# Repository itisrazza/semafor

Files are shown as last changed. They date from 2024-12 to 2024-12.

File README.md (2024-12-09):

# Semafor

This is the code and resources for a wee traffic light project I'm working on.

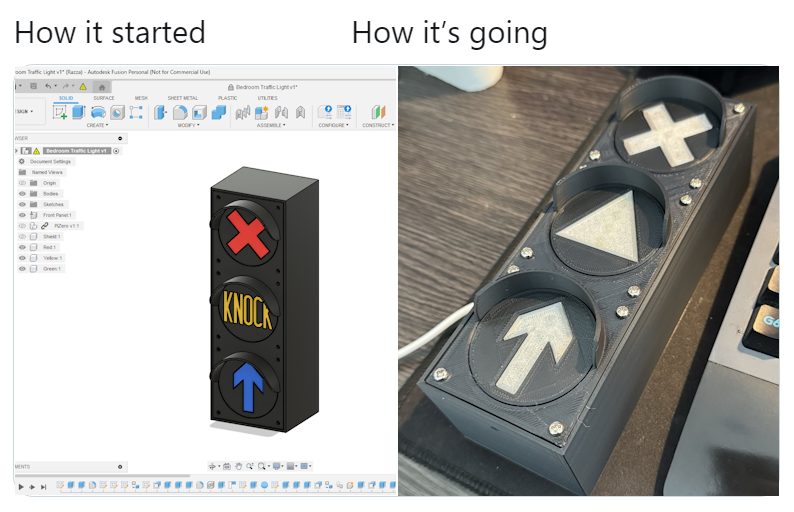
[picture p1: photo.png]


I've already built it, but I need to put together some nice photos of it. Here's a link to the [hardware README](hardware/README.md) if you want to build your own.

## Licence

This is a hobby project, and I encourage you to copy it and do whatever, but please credit, share alike and all that:

[Software](semafor) is licenced under the [GNU Affero General Public License v3+](LICENCE.AGPLv3+)

Everything else is [CC BY-SA 4.0](LICENCE.CC-BY-SA-4).

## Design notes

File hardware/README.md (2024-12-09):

# Semafor Hardware

## Bill of Meterials

Below are the things I used to put it together.

- 3D Printing Filament

  - Black PLA
  - Translucent PETG

- Electronics

  - [Raspberry Pi Zero W](https://www.pbtech.co.nz/product/SEVRBP0412/Raspberry-Pi-Zero-W-1GHz-BCM2835-Single-Core-CPU-5) with GPIO headers, and an SD card
  - [LEDs](https://www.aliexpress.com/item/1005003323707856.html)
    - 5x Red LEDs
    - 4x Yellow LEDs
    - 4x Green LEDs
  - [Prototype boards](https://www.aliexpress.com/item/1005006046334726.html)
    - 1x 2x8cm
    - 1x 3x7cm
  - 3x 330&Omega; resistors
  - [Any to Female Dupont Cable](https://www.aliexpress.com/item/1005005501503609.html)

- a number of M3x6mm and M3x10mm screws

## Build Instrucutions

### LED Assemblies

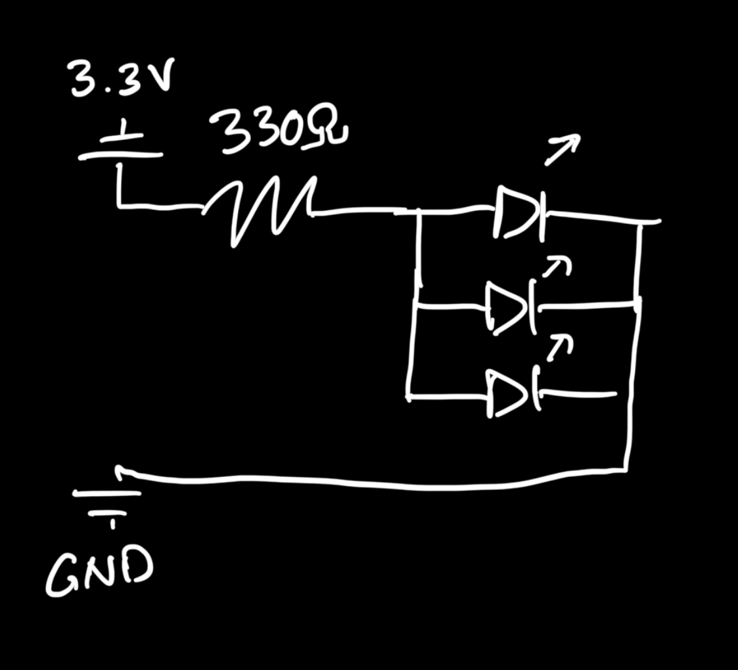
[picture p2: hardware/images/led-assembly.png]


The clear LED prints show what the spacing between the LEDs should be. Place them on the prototype-boards accordingly and connect them in parallel.

Add a 330&Omega; resistor in between the 3.3V power input and the LED power rail.

The power cables have a female Dupont connector on the Raspberry Pi end so they can be replace should the LEDs burn out, or a new design is desired.

Use [hot glue liberally](images/hot-glue.png) (optional, but I didn't have my own custom printed PCBs and didn't want to short anything by accident).

### Main Assembly

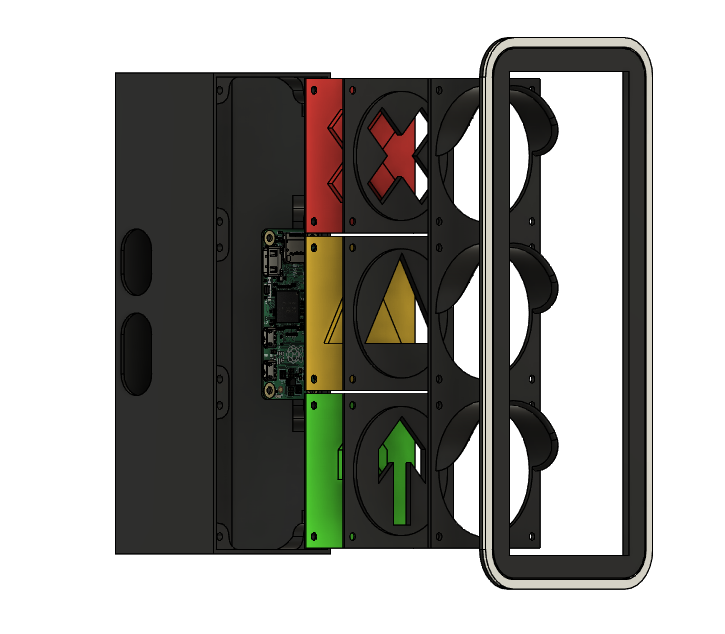
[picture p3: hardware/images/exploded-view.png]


1. Install the Raspberry Pi Zero into the Enclosure with 4 M3x6mm screws
2. Connect the LED assemblies to the following pins:
   - Red to [GPIO 17](https://pinout.xyz/pinout/pin11_gpio17/)
   - Yellow to [GPIO 27](https://pinout.xyz/pinout/pin13_gpio27/)
   - Green to [GPIO 22](https://pinout.xyz/pinout/pin15_gpio22/)
   - Grounds to [any ground pin](https://pinout.xyz/pinout/ground)
3. You may want to boot up the Pi and make sure everything works\
   (You can just use Python and the builtin `gpiozero` library)
4. Place the LED masks and front panel over the front.
5. Screw in place with 12 M3x6mm

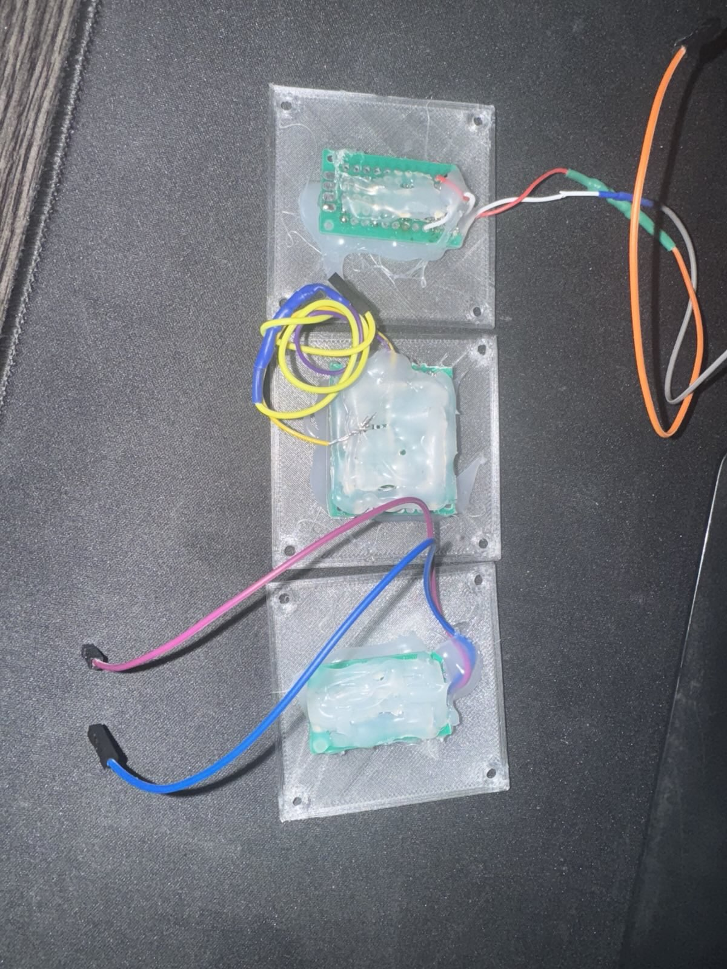
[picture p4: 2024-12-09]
hardware/images/hot-glue.png

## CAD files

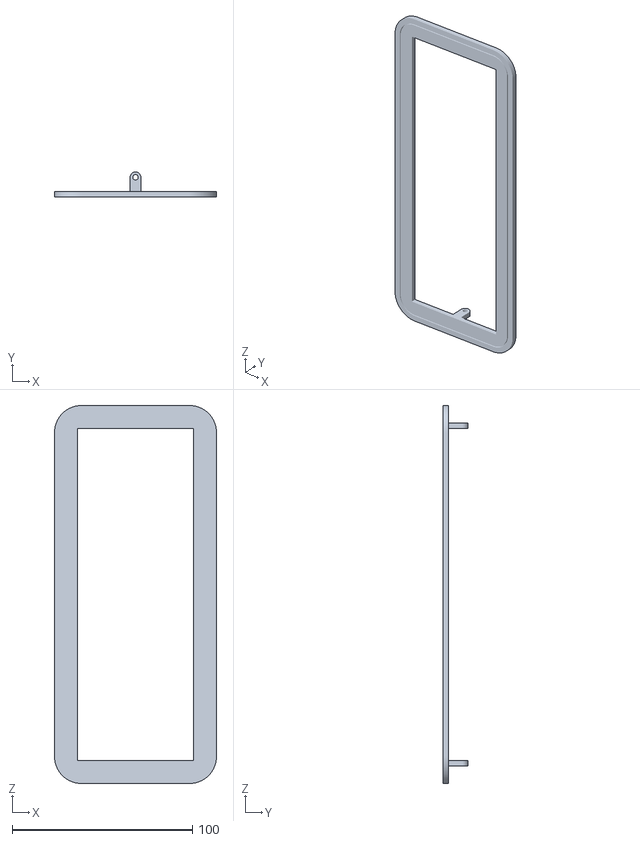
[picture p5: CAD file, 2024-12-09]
hardware/stl/Shield.stl
90.0 x 14.0 x 210.0

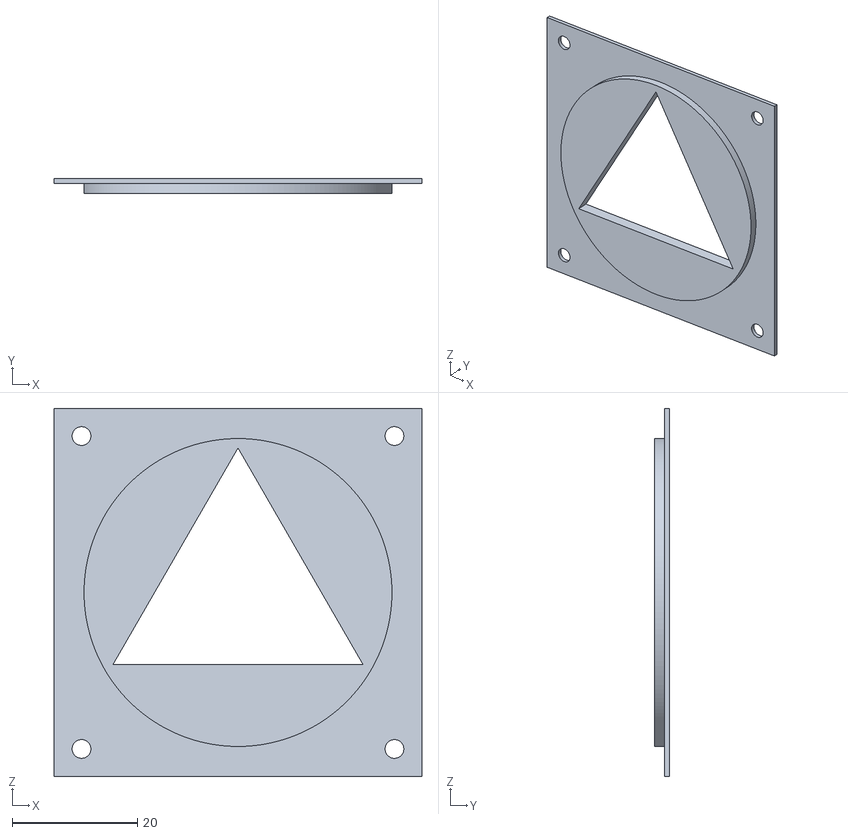
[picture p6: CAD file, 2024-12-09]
hardware/stl/Yellow Mask.stl
58.8 x 2.40 x 58.8

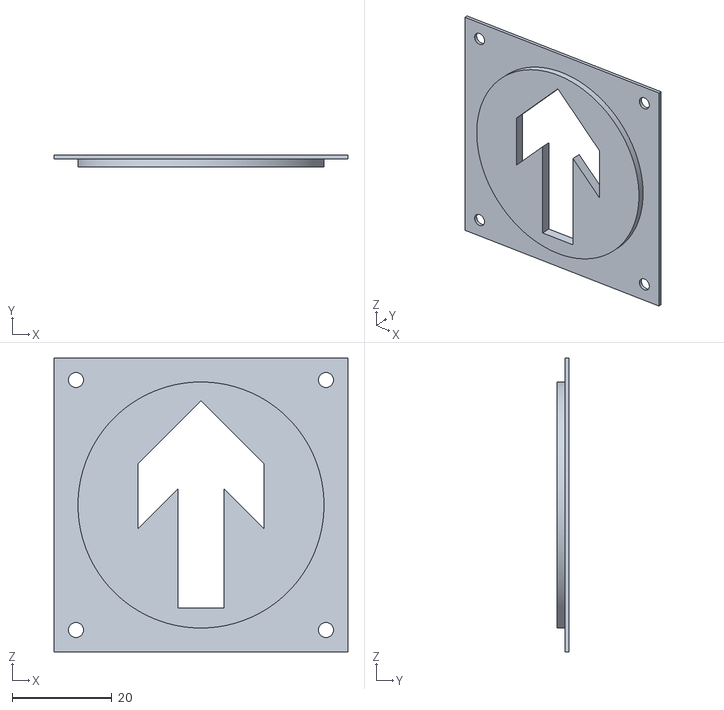
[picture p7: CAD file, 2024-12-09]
hardware/stl/Green Mask.stl
58.8 x 2.40 x 58.8

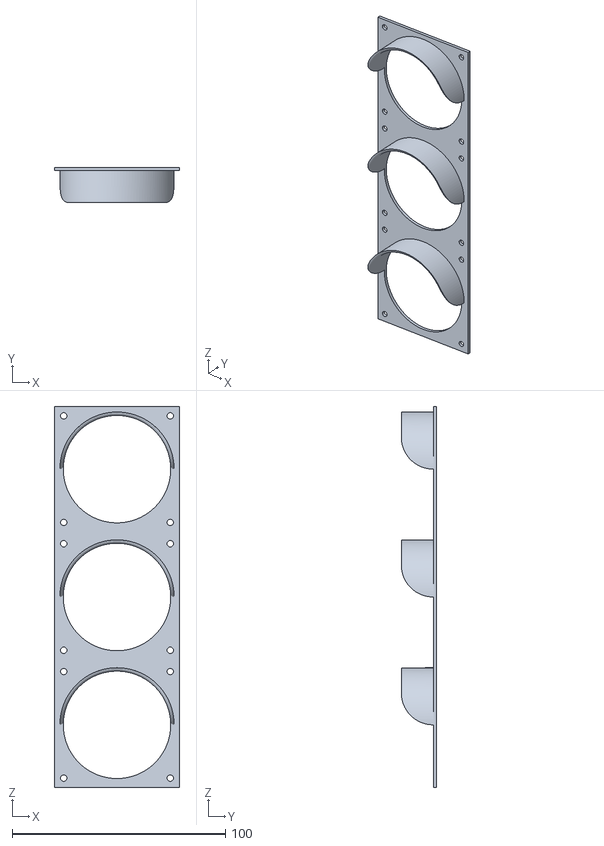
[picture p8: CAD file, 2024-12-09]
hardware/stl/Front Panel.stl
58.8 x 16.6 x 178.8

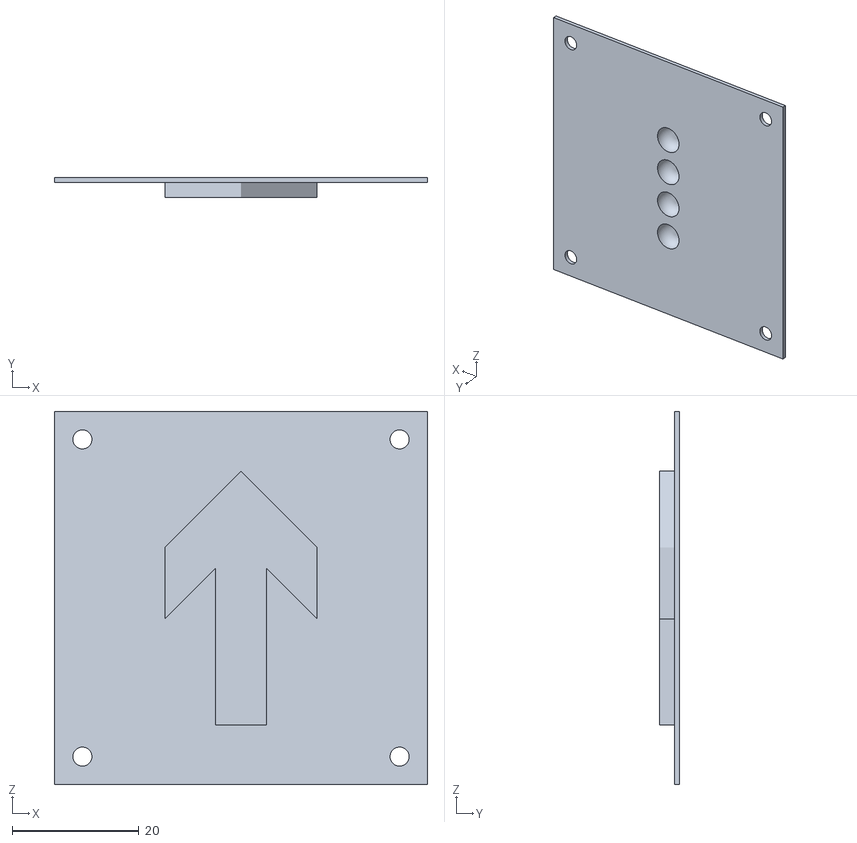
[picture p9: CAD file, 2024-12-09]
hardware/stl/Green Clear.stl
58.8 x 3.20 x 58.8

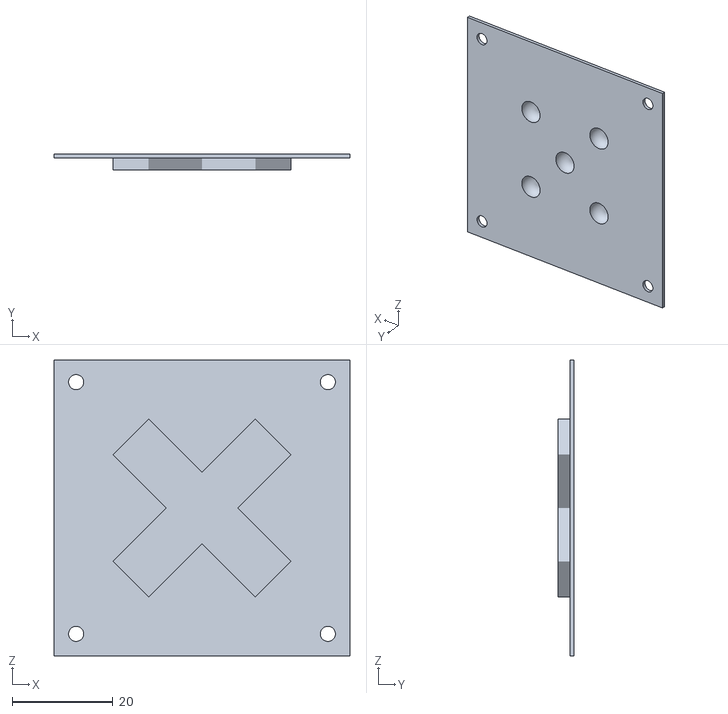
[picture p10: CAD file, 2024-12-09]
hardware/stl/Red Clear.stl
58.8 x 3.20 x 58.8

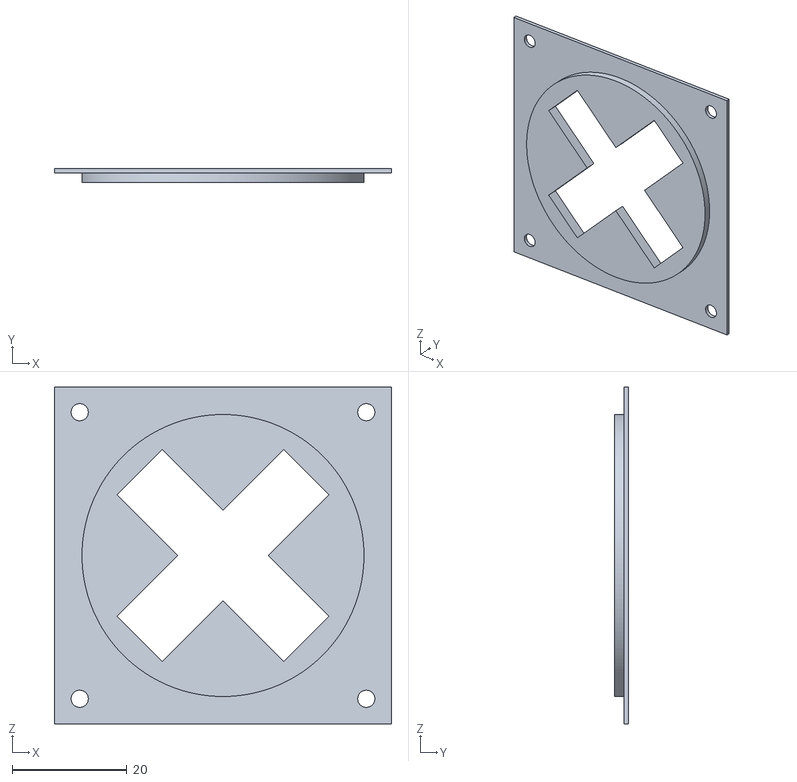
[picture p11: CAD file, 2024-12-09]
hardware/stl/Red Mask.stl
58.8 x 2.40 x 58.8

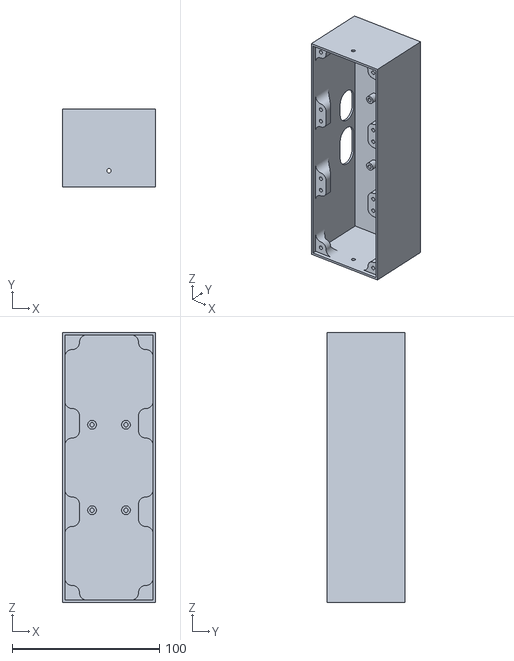
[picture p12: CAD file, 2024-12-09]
hardware/stl/Enclosure.stl
63.2 x 52.8 x 183.2

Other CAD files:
hardware/stl/Yellow Clear.stl

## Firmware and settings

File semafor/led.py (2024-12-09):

# Copyright (C) 2024 Raresh Nistor
#
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
from sys import stderr
from os import environ
from threading import Thread
from time import sleep
from enum import StrEnum
from typing import Union

if environ.get("SEMAFOR_GPIO_ENABLE", "0") == "1":
    from gpiozero import LED


LIGHT_COLORS = ["red", "yellow", "green"]


class LEDState(StrEnum):
    ON = "on"
    OFF = "off"
    BLINK = "blink"


class MockLED:
    def __init__(self, name: str):
        self.name = name

    def on(self):
        print(f"{repr(self)}.on()")

    def off(self):
        print(f"{repr(self)}.off()")

    def toggle(self):
        print(f"{repr(self)}.toggle()")

    def __repr__(self):
        return f"{type(self).__name__}(name={self.name})"


class LEDController:
    def __init__(self):
        self.lights = {color: LEDState.OFF for color in LIGHT_COLORS}
        self._prev_lights = dict(self.lights)

        self._leds = {
            color: self._gpio_or_mock(f"SEMAFOR_GPIO_{color.upper()}")
            for color in LIGHT_COLORS
        }

        self._runtime_thread = Thread(
            name="Semafor GPIO Control Thread",
            target=self._thread_main,
        )

    def start(self):
        self._runtime_thread.start()

    @staticmethod
    def _gpio_or_mock(env_pin: str) -> Union[MockLED, "LED"]:
        if environ.get("SEMAFOR_GPIO_ENABLE", "0") != "1":
            return MockLED(env_pin)

        try:
            pin = int(environ[env_pin])
        except KeyError:
            print(
                f"{env_pin} is not set. Defaulting to virtual LED.",
                file=stderr,
            )
            return MockLED(env_pin)
        except ValueError as e:
            print(
                f"Value for {env_pin} is invalid: {str(e)}",
                file=stderr,
            )
            return MockLED(env_pin)

        return LED(pin)

    def _thread_main(self):
        print("started LEDController thread")
        while True:
            self._update_pins()
            self._blink_leds()
            sleep(0.5)

    def _update_pins(self):
        if self._prev_lights == self.lights:
            return

        for color in LIGHT_COLORS:
            if self.lights[color] == LEDState.OFF:
                self._leds[color].off()
            else:
                self._leds[color].on()  # blink starts with on

        self._prev_lights = dict(self.lights)

    def _blink_leds(self):
        for color, state in self.lights.items():
            if state == LEDState.BLINK:
                self._leds[color].toggle()

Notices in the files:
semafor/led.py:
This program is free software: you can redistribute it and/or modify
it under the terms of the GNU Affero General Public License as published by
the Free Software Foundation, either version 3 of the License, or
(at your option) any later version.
